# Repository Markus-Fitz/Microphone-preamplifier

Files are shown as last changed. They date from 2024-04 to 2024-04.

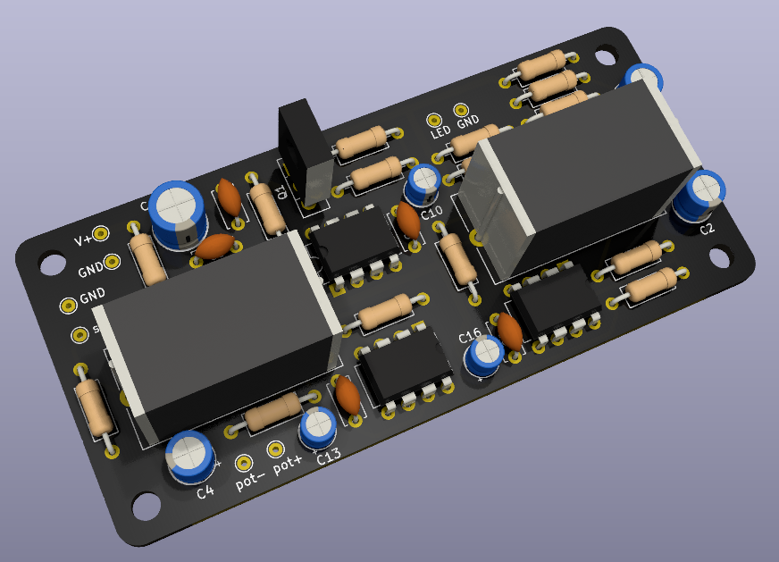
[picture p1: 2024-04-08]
rendering_top.png

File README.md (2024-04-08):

# Microphone-preamplifier
 Preamplifier for an electret microphone capsule.

# Description
 The circuit consists of two OpAmp-stages which together have around 24dB gain. The OpAmps chosen for this project are OP27-OpAmps for their DIP8-package and relatively high gain-bandwidth-product. The Coupling-capacitors are foil-capacitors, to minimizie their impact on the sonic performance. The Amplifier is designed to work off of a 12V power-supply, which is regulated down to 8V with an internal linear regulator. An optional gain-adjustment can be fitted to the second gain stage.

 # Specs
  The simulated Bode-plot of the amplifier shows a flat gain-curve (-1dB relative to 1kHz) from <10Hz to >200kHz.

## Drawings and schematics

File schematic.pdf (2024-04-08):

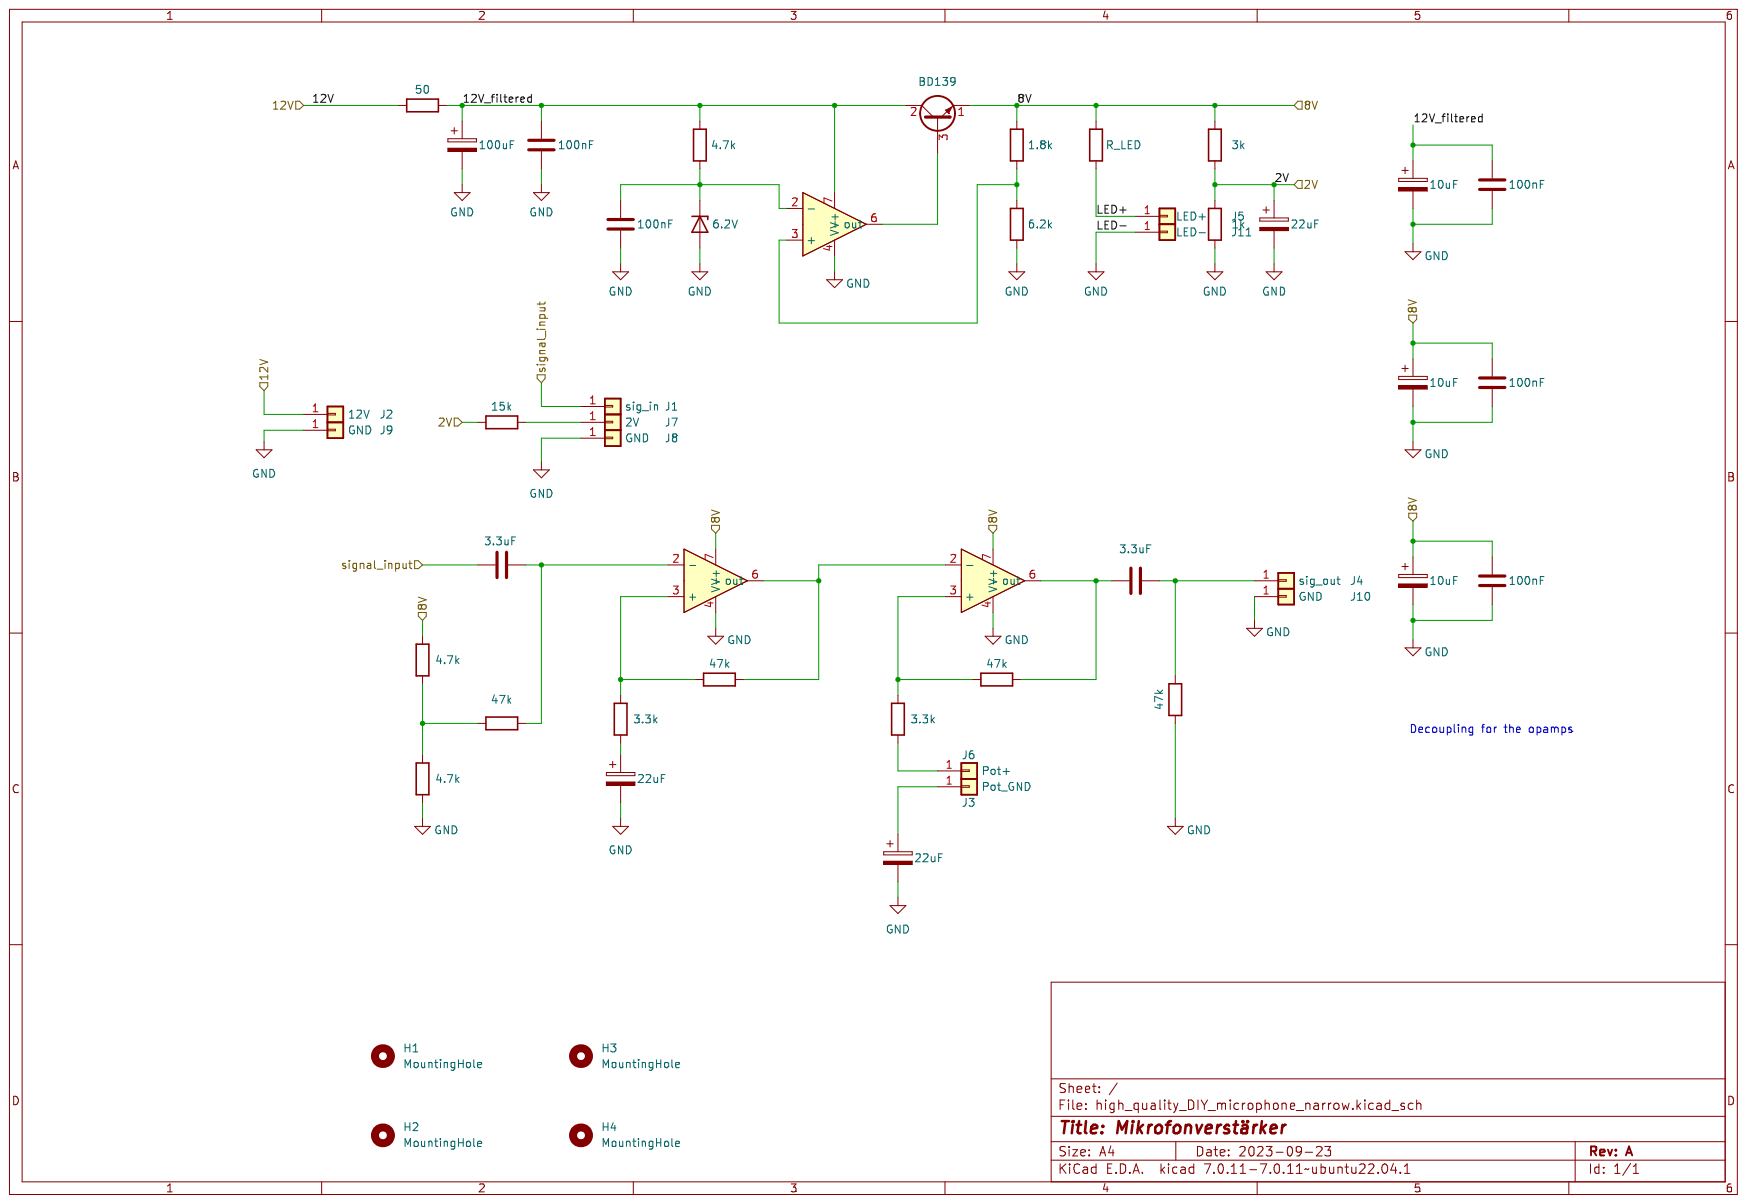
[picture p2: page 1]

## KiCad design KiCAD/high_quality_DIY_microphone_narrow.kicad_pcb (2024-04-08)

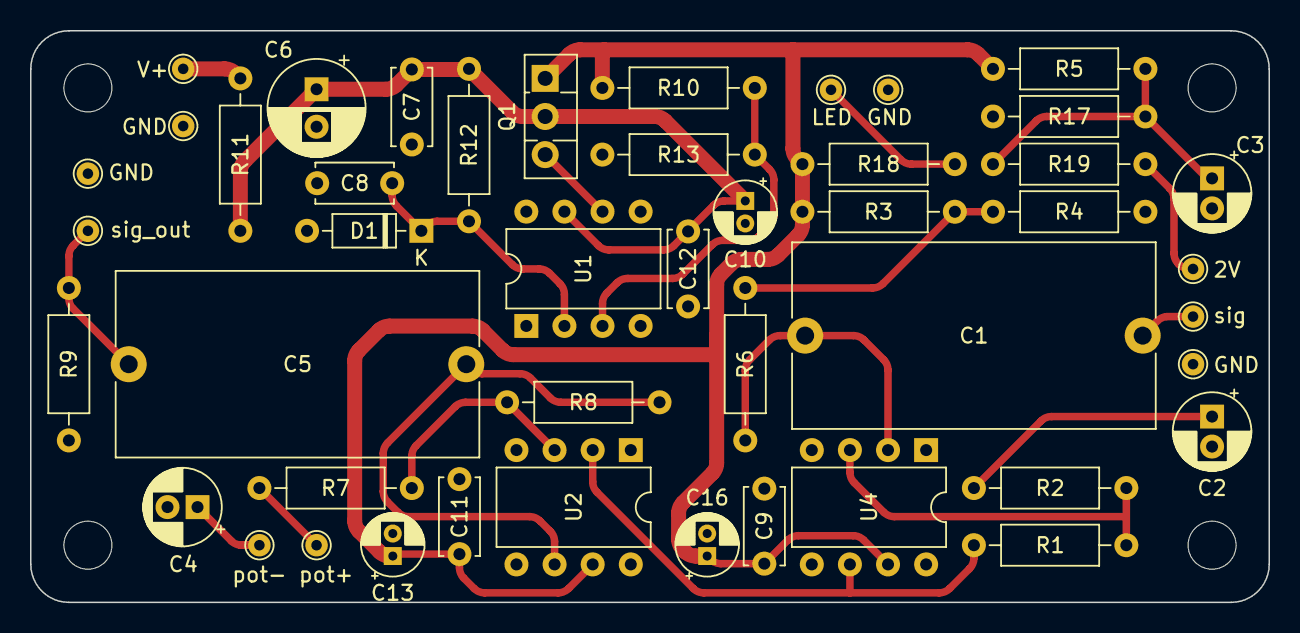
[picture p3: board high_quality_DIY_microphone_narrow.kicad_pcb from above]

Board: 2 copper layers, 82.6 x 38.1 mm, 50 parts (0 on the bottom side), 21 nets.

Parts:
C1, C5: 3.3uF; C_Rect_L24.0mm_W12.2mm_P22.50mm_MKT
C2, C3, C4: 22uF; CP_Radial_D5.0mm_P2.00mm
C6: 100uF; CP_Radial_D6.3mm_P2.50mm
C7, C8, C9, C11, C12: 100nF; C_Disc_D5.0mm_W2.5mm_P5.00mm
C10, C13, C16: 10uF; CP_Radial_D4.0mm_P1.50mm
D1: 6.2V; D_DO-35_SOD27_P7.62mm_Horizontal
H1, H2, H3, H4: MountingHole; MountingHole_3.2mm_M3_DIN965
J1: sig_in; TestPoint_THTPad_D1.5mm_Drill0.7mm
J2: 12V; TestPoint_THTPad_D1.5mm_Drill0.7mm
J3: Pot_GND; TestPoint_THTPad_D1.5mm_Drill0.7mm
J4: sig_out; TestPoint_THTPad_D1.5mm_Drill0.7mm
J5: LED+; TestPoint_THTPad_D1.5mm_Drill0.7mm
J6: Pot+; TestPoint_THTPad_D1.5mm_Drill0.7mm
J7: 2V; TestPoint_THTPad_D1.5mm_Drill0.7mm
J8, J9, J10: GND; TestPoint_THTPad_D1.5mm_Drill0.7mm
J11: LED-; TestPoint_THTPad_D1.5mm_Drill0.7mm
Q1: BD139; TO-126-3_Vertical
R1, R6, R8, R9: 47k; R_Axial_DIN0207_L6.3mm_D2.5mm_P10.16mm_Horizontal
R2, R7: 3.3k; R_Axial_DIN0207_L6.3mm_D2.5mm_P10.16mm_Horizontal
R3, R4, R12: 4.7k; R_Axial_DIN0207_L6.3mm_D2.5mm_P10.16mm_Horizontal
R5: 3k; R_Axial_DIN0207_L6.3mm_D2.5mm_P10.16mm_Horizontal
R10: 1.8k; R_Axial_DIN0207_L6.3mm_D2.5mm_P10.16mm_Horizontal
R11: 50; R_Axial_DIN0207_L6.3mm_D2.5mm_P10.16mm_Horizontal
R13: 6.2k; R_Axial_DIN0207_L6.3mm_D2.5mm_P10.16mm_Horizontal
R17: 1k; R_Axial_DIN0207_L6.3mm_D2.5mm_P10.16mm_Horizontal
R18: R_LED; R_Axial_DIN0207_L6.3mm_D2.5mm_P10.16mm_Horizontal
R19: 15k; R_Axial_DIN0207_L6.3mm_D2.5mm_P10.16mm_Horizontal
U1, U2, U4: DIP-8_W7.62mm

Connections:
/2V: C3.1, R5.1, R17.2, R19.1
/8V: C9.1, C11.1, C13.1, C16.1, Q1.1 (E), R3.2, R5.2, R10.2, R18.2, U2.7 (V+), U4.7 (V+)
/12V: J2.1, R11.1
/12V_filtered: C6.1, C7.1, C10.1, C12.1, Q1.2 (C), R11.2, R12.2, U1.7 (V+)
/LED+: J5.1, R18.1
/signal_input: C1.1, J1.1
GND: C2.2, C3.2, C4.2, C6.2, C7.2, C8.2, C9.2, C10.2, C11.2, C12.2, C13.2, C16.2, D1.2 (A), J8.1, J9.1, J10.1, J11.1, R4.1, R9.1, R13.1, R17.1, U1.4 (V-), U2.4 (V-), U4.4 (V-)
unnamed: C2.1, R2.1
unnamed: C8.1, D1.1 (K), R12.1, U1.2 (-)
unnamed: C4.1, J3.1
unnamed: C5.2, J4.1, R9.2
unnamed: J6.1, R7.1
unnamed: J7.1, R19.2
unnamed: Q1.3 (B), U1.6 (out)
unnamed: R3.1, R4.2, R6.1
unnamed: R10.1, R13.2, U1.3 (+)
unnamed: R7.2, R8.1, U2.3 (+)
unnamed: R1.2, U2.2 (-), U4.6 (out)
unnamed: C5.1, R8.2, U2.6 (out)
unnamed: R1.1, R2.2, U4.3 (+)
unnamed: C1.2, R6.2, U4.2 (-)

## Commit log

2024-04-08 Initial Commit.
    Initial Commit.
    [high_quality_DIY_microphone_narrow.kicad_pcb, high_quality_DIY_microphone_narrow.kicad_sch]
2024-04-08 Update README.md
    Extended Readme to include a description of the circuit and its basic specs.
2024-04-08 Cleanup
    Cleanup of KiCAD-folder.
